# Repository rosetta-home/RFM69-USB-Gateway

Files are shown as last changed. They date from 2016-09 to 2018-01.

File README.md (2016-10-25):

# RFM69-USB-Gateway
This is a USB gateway for the RFM69 FSK module. Incoming wireless data is sent to the host computer over serial.

<p align="center">
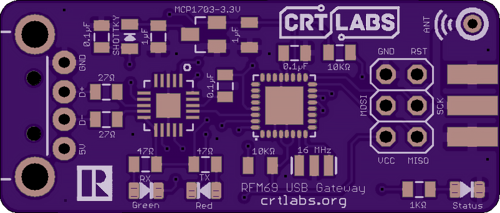
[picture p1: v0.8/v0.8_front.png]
OSH Park PCB render - front
  
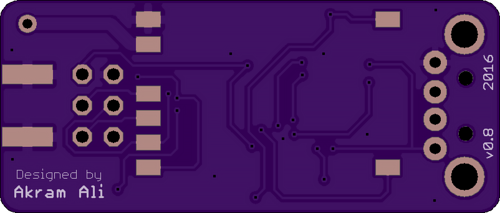
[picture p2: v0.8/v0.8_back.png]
OSH Park PCB render - back
  
</p>

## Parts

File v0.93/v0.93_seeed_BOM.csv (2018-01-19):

Designator | Manufacturer Part Number | Quantity
C1, C5, C6 | CC0805KRX7R9BB104 | 3
R1 | RC0805FR-0710KL | 1
R7 | RC0805FR-0710KL | 1
X1 | CSTCE16M0V53-R0 | 1
R2 | RC0805FR-071KL | 1
C2, C4 | CC0805ZRY5V8BB105 | 2
R3, R5 | RC0805FR-0727RL | 2
R4, R6 | RC0805FR-0747RL | 2
U2 | ATMEGA328P-MU | 1
FT231XQ-R | FT231XQ-R | 1
RX | LG R971-KN-1 | 1
IC3 | MCP1703T-3302E/CB | 1
U1 | RFM69HCW | 1
TX | LG R971-KN-1 | 1
D | SD0805S040S0R5 | 1
U$2 | LG R971-KN-1 | 1

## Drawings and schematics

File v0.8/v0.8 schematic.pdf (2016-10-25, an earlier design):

U2

A

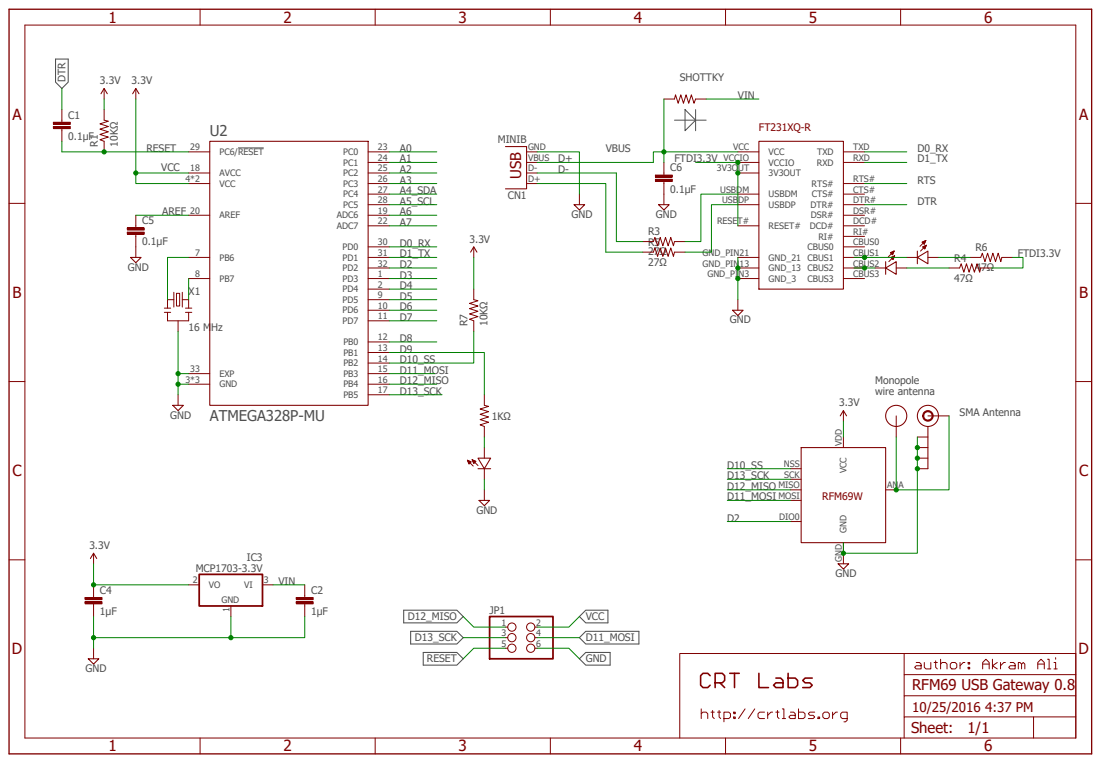
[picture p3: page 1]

VCC VDD GND GND DIO0

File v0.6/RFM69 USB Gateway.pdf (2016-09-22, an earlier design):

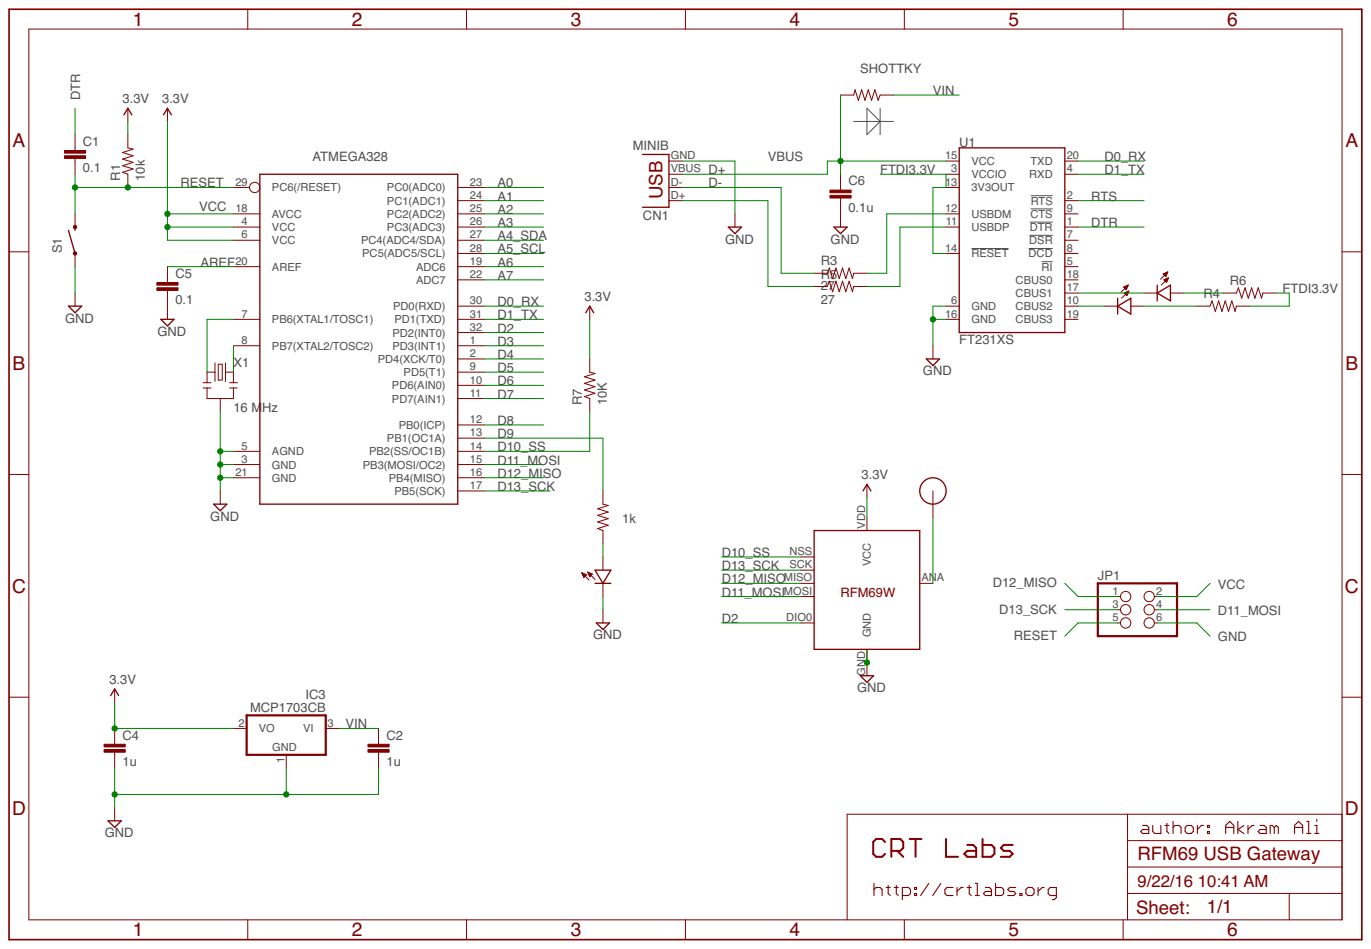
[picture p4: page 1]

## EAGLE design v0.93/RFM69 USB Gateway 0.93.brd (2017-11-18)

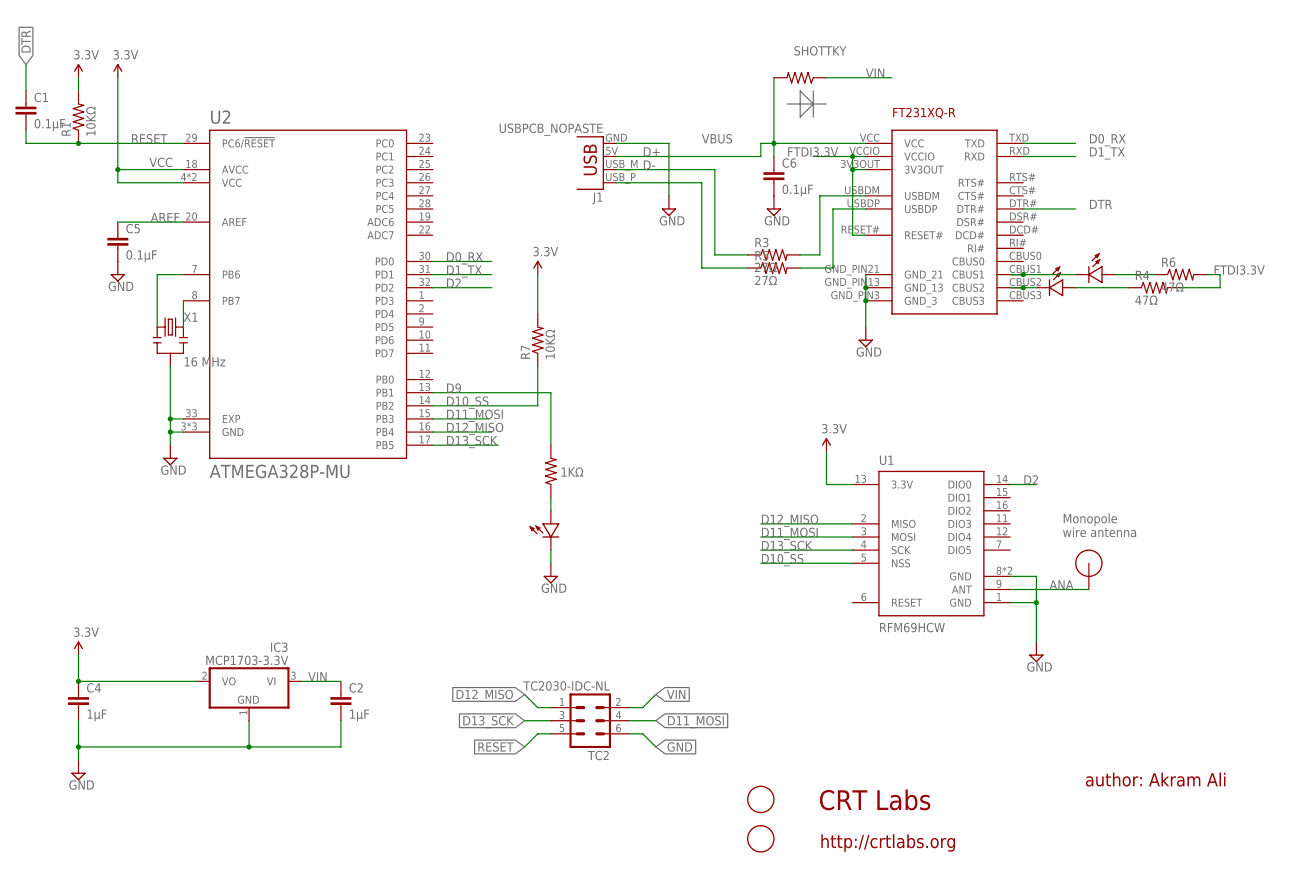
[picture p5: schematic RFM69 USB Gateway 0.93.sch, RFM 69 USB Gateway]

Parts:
C1, C5, C6: 0.1μF; 0805; MPN CC0805KRX7R9BB104
C2, C4: 1μF; 0805; MPN CC0805ZRY5V8BB105
D: SHOTTKY; 0805; MPN SD0805S040S0R5
FT231XQ-R: FT231XQ-R; FTDI_FT231XQ-R_PACKAGE; MPN FT231XQ-R
IC3: MCP1703-3.3V; SOT23; MPN MCP1703T-2502E/CB
J1: USBPCB_NOPASTE; USB-A-PCB-NOPASTE
R1, R7: 10KΩ; 0805; MPN RC0805FR-0710KL
R2: 1KΩ; 0805; MPN RC0805FR-071KL
R3, R5: 27Ω; 0805; MPN RC0805FR-0727RL
R4, R6: 47Ω; 0805; MPN RC0805FR-0747RL
RX: Green; 0805-LED; MPN LG R971-KN-1
TC2: TC2030-IDC-NL
TX: Red; 0805-LED; MPN LG R971-KN-1
U1: RFM69HCW; RFM69HCW-XXXS2; MPN RFM69HW
U2: ATMEGA328P-MU; QFN50P500X500X100-33N; MPN ATmega328P-MU
U$2: Status; 0805-LED; MPN LG R971-KN-1
U$3, U$4: FIDUCIAL; FIDUCIAL_1MM
U$6: RFM12B_ANTENNA; RFM12B-ANTENNA
X1: 16 MHz; RESONATOR-SMD; MPN CSTCE16M0V53-R0

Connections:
ANA: U1.9 (ANT), U$6.P$1
AREF: C5.1, U2.20 (AREF)
D0_RX: FT231XQ-R.TXD, U2.30 (PD0)
D1_TX: FT231XQ-R.RXD, U2.31 (PD1)
D2: U1.14 (DIO0), U2.32 (PD2)
D9: R2.2, U2.13 (PB1)
D10_SS: R7.1, U1.5 (NSS), U2.14 (PB2)
D11_MOSI: TC2.4, U1.3 (MOSI), U2.15 (PB3)
D12_MISO: TC2.1, U1.2 (MISO), U2.16 (PB4)
D13_SCK: TC2.3, U1.4 (SCK), U2.17 (PB5)
D+: J1.USB_P (D+), R5.1
D-: J1.USB_M (D-), R3.1
DTR: C1.1, FT231XQ-R.DTR#
FTDI3.3V: FT231XQ-R.3V3OUT, FT231XQ-R.RESET#, FT231XQ-R.VCCIO, R4.2, R6.2
GND: C2.2, C4.2, C5.2, C6.2, FT231XQ-R.GND_PIN3 (GND_3), FT231XQ-R.GND_PIN13 (GND_13), FT231XQ-R.GND_PIN21 (GND_21), IC3.1 (GND), J1.GND, TC2.6, U1.1 (GND), U1.8 (GND), U1.10 (GND), U2.3 (GND), U2.5 (GND), U2.21 (GND), U2.33 (EXP), U$2.MINUS, X1.2
unnamed: U2.7 (PB6), X1.1
unnamed: R2.1, U$2.PLUS
unnamed: FT231XQ-R.USBDM, R3.2
unnamed: FT231XQ-R.USBDP, R5.2
unnamed: FT231XQ-R.CBUS1, RX.MINUS
unnamed: FT231XQ-R.CBUS2, TX.MINUS
unnamed: R4.1, TX.PLUS
unnamed: R6.1, RX.PLUS
unnamed: U2.8 (PB7), X1.3
RESET: C1.2, R1.1, TC2.5, U2.29 (PC6/!RESET)
VBUS: C6.1, D.2, FT231XQ-R.VCC, J1.5V (VBUS)
VCC: C4.1, IC3.2 (VO), R1.2, R7.2, U1.13 (3.3V), U2.4 (VCC), U2.6 (VCC), U2.18 (AVCC)
VIN: C2.1, D.1, IC3.3 (VI), TC2.2

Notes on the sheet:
CRT Labs
author: Akram Ali
http://crtlabs.org
Monopole wire antenna

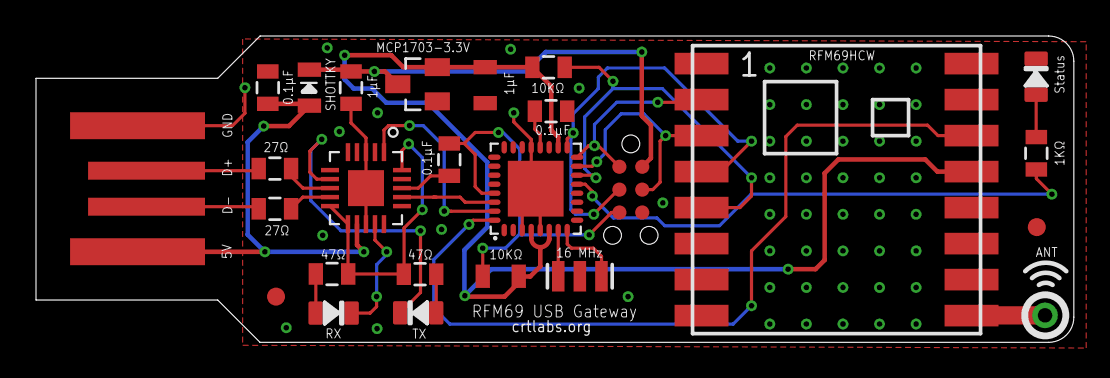
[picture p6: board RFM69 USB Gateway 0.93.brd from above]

Board: 2 copper layers, 57.7 x 17.0 mm, 26 parts (0 on the bottom side), 28 nets.

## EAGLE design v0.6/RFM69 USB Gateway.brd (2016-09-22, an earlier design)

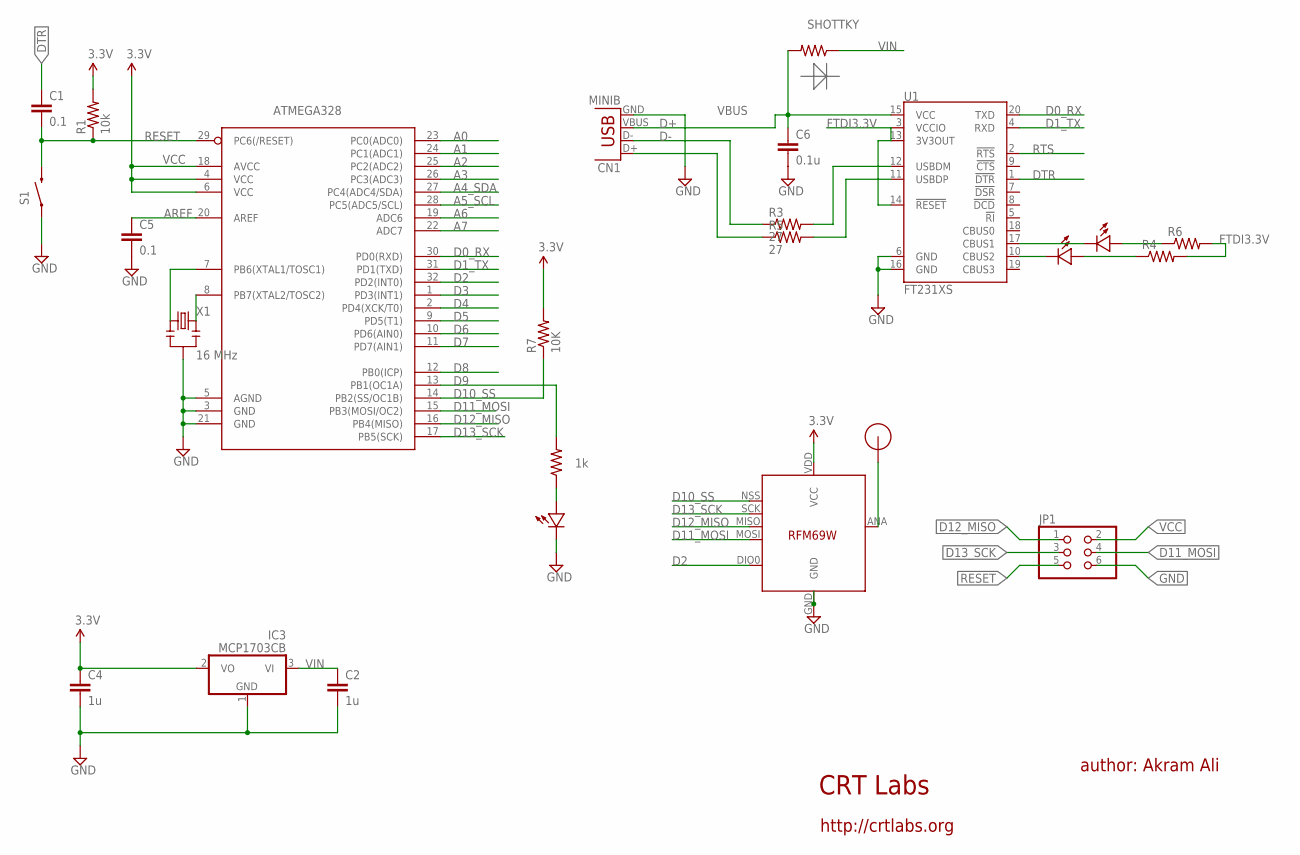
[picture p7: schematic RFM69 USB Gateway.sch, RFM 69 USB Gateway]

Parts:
ATMEGA328: ATMega-328; TQFP32-08
C1, C5: 0.1; 0805
C2, C4: 1u; 0805
C6: 0.1u; 0805
CN1: MINIB; USB-A-H
D: SHOTTKY; 0805
IC3: MCP1703CB; SOT23
JP1: PINHD-2X3; 2X03
R1: 10k; 0805
R2: 1k; 0805
R3, R5: 27; 0805
R4, R6: RESISTOR0805-RES; 0805
R7: 10K; 0805
S1: SWITCH-MOMENTARY-2SMD-ALT01; TACTILE-SWITCH-SMD-ALT01
U1: FT231XS; SSOP20_L
U$1: RFM12B_ANTENNA; RFM12B-ANTENNA
U$2, U$4, U$7: LED0805; 0805-LED
U$5: RFM69; RFM69W-MINPADS
X1: 16 MHz; RESONATOR-SMD

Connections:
A0: ATMEGA328.23 (PC0(ADC0))
A1: ATMEGA328.24 (PC1(ADC1))
A2: ATMEGA328.25 (PC2(ADC2))
A3: ATMEGA328.26 (PC3(ADC3))
A4_SDA: ATMEGA328.27 (PC4(ADC4/SDA))
A5_SCL: ATMEGA328.28 (PC5(ADC5/SCL))
A6: ATMEGA328.19 (ADC6)
A7: ATMEGA328.22 (ADC7)
AREF: ATMEGA328.20 (AREF), C5.1
D0_RX: ATMEGA328.30 (PD0(RXD)), U1.20 (TXD)
D1_TX: ATMEGA328.31 (PD1(TXD)), U1.4 (RXD)
D2: ATMEGA328.32 (PD2(INT0)), U$5.DIO0
D3: ATMEGA328.1 (PD3(INT1))
D4: ATMEGA328.2 (PD4(XCK/T0))
D5: ATMEGA328.9 (PD5(T1))
D6: ATMEGA328.10 (PD6(AIN0))
D7: ATMEGA328.11 (PD7(AIN1))
D8: ATMEGA328.12 (PB0(ICP))
D9: ATMEGA328.13 (PB1(OC1A)), R2.2
D10_SS: ATMEGA328.14 (PB2(SS/OC1B)), R7.1, U$5.NSS (SEL)
D11_MOSI: ATMEGA328.15 (PB3(MOSI/OC2)), JP1.4, U$5.MOSI
D12_MISO: ATMEGA328.16 (PB4(MISO)), JP1.1, U$5.MISO
D13_SCK: ATMEGA328.17 (PB5(SCK)), JP1.3, U$5.SCK
D+: CN1.D+, R5.1
D-: CN1.D-, R3.1
DTR: C1.1, U1.1 (!DTR)
FTDI3.3V: R4.2, R6.2, U1.3 (VCCIO), U1.13 (3V3OUT), U1.14 (!RESET)
GND: ATMEGA328.3 (GND), ATMEGA328.5 (AGND), ATMEGA328.21 (GND), C2.2, C4.2, C5.2, C6.2, CN1.GND, IC3.1 (GND), JP1.6, S1.1, S1.2 (1), U1.6 (GND), U1.16 (GND), U$2.MINUS, U$5.GND, X1.2
unnamed: ATMEGA328.7 (PB6(XTAL1/TOSC1)), X1.1
unnamed: R2.1, U$2.PLUS
unnamed: U$1.P$1, U$5.ANA (ANT)
unnamed: R3.2, U1.12 (USBDM)
unnamed: R5.2, U1.11 (USBDP)
unnamed: U1.17 (CBUS1), U$4.MINUS
unnamed: U1.10 (CBUS2), U$7.MINUS
unnamed: R4.1, U$7.PLUS
unnamed: R6.1, U$4.PLUS
unnamed: ATMEGA328.8 (PB7(XTAL2/TOSC2)), X1.3
RESET: ATMEGA328.29 (PC6(/RESET)), C1.2, JP1.5, R1.1, S1.3 (2), S1.4 (2)
RTS: U1.2 (!RTS)
VBUS: C6.1, CN1.VBUS, D.2, U1.15 (VCC)
VCC: ATMEGA328.4 (VCC), ATMEGA328.6 (VCC), ATMEGA328.18 (AVCC), C4.1, IC3.2 (VO), JP1.2, R1.2, R7.2, U$5.VDD (VCC)
VIN: C2.1, D.1, IC3.3 (VI)

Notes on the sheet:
CRT Labs
author: Akram Ali
http://crtlabs.org

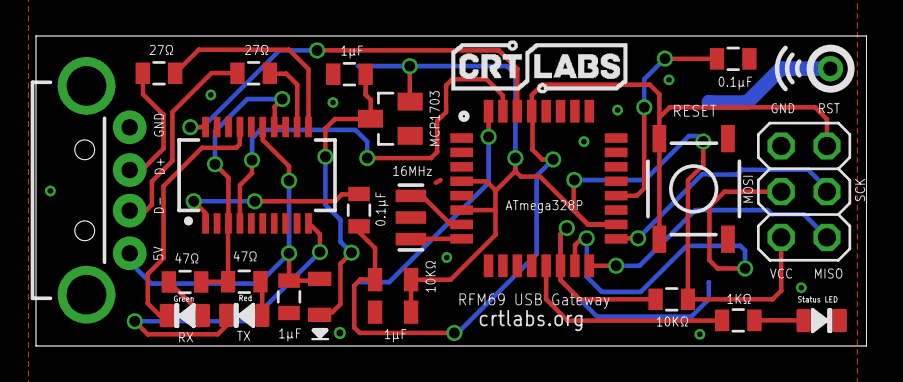
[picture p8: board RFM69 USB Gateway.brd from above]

Board: 2 copper layers, 46.1 x 17.2 mm, 25 parts (1 on the bottom side), 28 nets.

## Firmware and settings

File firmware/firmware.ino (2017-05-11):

#include <RFM69.h>         //get it here: http://github.com/lowpowerlab/rfm69
#include <SPIFlash.h>      //get it here: http://github.com/lowpowerlab/spiflash
#include <SPI.h>           //comes with Arduino IDE (www.arduino.cc)
#include "config.h"

#define NETWORKID     101
#define FREQUENCY     RF69_915MHZ //Match this with the version of your Moteino! (others: RF69_433MHZ, RF69_868MHZ)
#define IS_RFM69HW    //uncomment only for RFM69HW! Leave out if you have RFM69W!
#define LED             9
#define FLASH_CS        8
#define SERIAL_BAUD 115200
#define SERIAL_EN     //comment out if you don't want any serial verbose output
#define ACK_TIME       30  // # of ms to wait for an ack
//*****************************************************************************************************************************

RFM69 radio;
SPIFlash flash(FLASH_CS, 0xEF30); //EF40 for 16mbit windbond chip
char data[100];
char _rssi[5];

void setup()
{
  pinMode(10, OUTPUT);
  Serial.begin(115200);

  radio.initialize(FREQUENCY,NODEID,NETWORKID);
#ifdef IS_RFM69HW
  radio.setHighPower(); //uncomment only for RFM69HW!
#endif
  radio.encrypt(ENCRYPTKEY);
  flash.initialize();
}

void loop()
{
  if (radio.receiveDone())
  {
    int rssi = radio.RSSI;

    if (radio.DATALEN > 0)
    {
      for (byte i = 0; i < radio.DATALEN; i++)
        data[i] = (char)radio.DATA[i];
    }

    dtostrf(rssi, 3, 0, _rssi);
    strcat(data, ",r:");
    strcat(data, _rssi);

    if (radio.ACKRequested())
    {
      byte theNodeID = radio.SENDERID;
      radio.sendACK();

      Serial.println(data);
      delay(1);

      memset(data, 0, sizeof data);
      memset(_rssi, 0, sizeof _rssi);

      Blink(LED,10);
    }
  }
}

void Blink(byte PIN, int DELAY_MS)
{
  pinMode(PIN, OUTPUT);
  digitalWrite(PIN,HIGH);
  delay(DELAY_MS);
  digitalWrite(PIN,LOW);
}

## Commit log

2016-07-01 Eagle files for USB gateway
    v0.2
    [RFM69 USB Gateway.brd, RFM69 USB Gateway.sch]
2016-07-15 USB jack adjustments
    v0.3 - Adjusted edge of board a little to accommodate groove of USB jack
2016-07-21 Added ISP header and reset button
    v0.4
    - ISP header
    - Reset button
    - Silk screen for all components
    - Slight rearrangement
    [RFM69 USB Gateway.brd, RFM69 USB Gateway.sch]
2016-07-21 Fixed overlapping traces
    [RFM69 USB Gateway.brd]
2016-07-21 OSH Park PCB layout
2016-08-03 Added pullup on CS line
    10K pullup on CS for allowing ISP programming
    Changed all components to 0805 size
    [RFM69%20USB%20Gateway.brd, RFM69%20USB%20Gateway.sch]
2016-08-03 Silkscreen minor edits
    [RFM69%20USB%20Gateway.brd]
2016-08-03 Added pullup on CS (pin 10)
    10K pullup on CS (RFM69) to avoid issues during ISP programming
    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
    [RFM69 USB Gateway.brd, RFM69 USB Gateway.sch]
2016-08-03 PCB render from oshpark.com
2016-09-08 PDF schematic added
2016-09-22 v0.6 - fixed auto reset, adjusted traces
    Added 0.1 uF cap on reset, series with DTR (allows auto reset via FTDI)
    Moved some components to accommodate the cap
    Adjusted several traces
    Made GND vias more consistent in size
    [RFM69 USB Gateway.brd, RFM69 USB Gateway.sch]
2016-09-22 Updated the PDF schematic
    v0.6
    [RFM69 USB Gateway.sch]
2016-09-22 Adjusted D- trace
2016-09-22 Minor silkscreen adjustments
    [RFM69 USB Gateway.brd]
2016-09-22 Added CRT Labs logo
    [RFM69 USB Gateway.brd]
2016-09-22 Added back PCB render
2016-09-22 v0.7 - added SMA connector
    Moved some components around to accommodate for SMA connector and clean
    up some traces
    [RFM69 USB Gateway 0.7.brd, RFM69 USB Gateway 0.7.sch]
2016-09-22 Touch up schematic
    [RFM69 USB Gateway 0.7.sch]
2016-09-22 Deleted old schematic
2016-09-22 Added v0.7 renders
    v0.7 has SMA antenna, some components moved a bit to accommodate for
    it. Board length is slightly longer than v0.6, but everything else is
    the same.
    [RFM69 USB Gateway 0.7.brd, RFM69 USB Gateway 0.7.sch]
2016-09-22 Rounded corners of board
    [RFM69 USB Gateway 0.7.brd, RFM69 USB Gateway 0.7.sch]
2016-10-18 v0.8 - Changed packages to QFN - **WIP**
    ! Traces not connected !
    [RFM69 USB Gateway 0.8.brd, RFM69 USB Gateway 0.8.sch]
2016-10-25 Routed all traces
    Rearranged components on the board
    [RFM69 USB Gateway 0.8.brd, RFM69 USB Gateway 0.8.sch]
2016-10-25 Deleted shrug emoji because no space :( but oh well ¯\_(ツ)_/¯
    [RFM69 USB Gateway 0.8.brd]
2016-10-25 Unsmashed and updated all component values
    [RFM69 USB Gateway 0.8.brd, RFM69 USB Gateway 0.8.sch]
2016-10-25 Fixed silkscreen
    Changed all fonts to vector; silkscreen now on layer 121, adjusted some
    components and traces
    [RFM69 USB Gateway 0.8.brd, RFM69 USB Gateway 0.8.sch]
2016-10-25 Adjusted silkscreen
    [RFM69 USB Gateway 0.8.brd, RFM69 USB Gateway 0.8.sch]
2016-10-25 Added REALTOR R to silkscreen
    [RFM69 USB Gateway 0.8.brd]
2016-10-25 Organized folders
    [RFM69 USB Gateway 0.7.brd, RFM69 USB Gateway 0.7.sch, RFM69 USB Gateway.brd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]
2016-10-25 Added PDF schematic for v0.8
2016-10-25 Minor trace adjustments
    [RFM69 USB Gateway 0.8.brd]
2017-02-06 v0.9 - Integrated USB jack into PCB
    - removed USB A jack and integrated into PCB. 2.4mm thickness required
    for a tight fit into USB port.
    - made VCC traces slightly thicker.
    [RFM69 USB Gateway 0.9.brd, RFM69 USB Gateway 0.9.sch]
2017-02-07 v0.91 moving RFM69 to top side
    traces still incomplete
    [RFM69 USB Gateway 0.91.brd, RFM69 USB Gateway 0.91.sch]
2017-02-07 Made ground pours on bottom more even
    Added extra stitching vias; changed very thin line-like pours to thicker
    and fatter (ish) ones; minor touchups
    [RFM69 USB Gateway 0.9.brd]
2017-02-13 Connected all traces
    [RFM69 USB Gateway 0.91.brd]
2017-03-16 Minor firmware update
    LED will only blink after ACK is requested and sent
2017-03-22 v0.92 - design update
    - Removed ISP headers (flash using MLF/QFN socket - for advanced users
    only) use v0.8 or v0.9 for ISP headers
    - Removed SMA pads (just use wire monopole 82mm for 915MHz)
    - Replaced RFM69HW with RFM69HCW
    - Reduced overall size of board
    - Rerouted several traces to fit new design
    - Massive GND plane stitching
    - Silkscreen adjustments
    - Schematic adjustments
    - Accounted for major errors in DRC and ERC (ignore drill size, trace
    width and clearance)
    - Relocated LED
    [RFM69 USB Gateway 0.92.brd, RFM69 USB Gateway 0.92.sch]
2017-03-22 Relocated a via
    for better silkscreen
    [RFM69 USB Gateway 0.92.brd]
2017-03-29 adding bom for v.92
    [RFM69 USB Gateway 0.92-BOM.csv]
2017-03-29 adding mpns to schematic
    [RFM69 USB Gateway 0.92.sch]
2017-03-30 updated mpn to ATmega328P-MU
    [RFM69 USB Gateway 0.92-BOM.csv]
2017-03-30 synchronized brd file
    [RFM69 USB Gateway 0.92.brd]
2017-04-03 Fixed mirrored logo
    lol how did that happen
    [RFM69 USB Gateway 0.92.brd]
2017-11-18 v0.93 update
    - Added tag connect ISP header for programming
    - board dimensions slightly increased to accomodate tag connect
    - Adjusted several traces to accomodate new header
    - Increased all via drill sizes to 12 mil (0.3mm)
    - Reduced thickness of USB part from 12.54mm to 12.30mm
    - minor silk screen adjustments
    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
    [RFM69 USB Gateway 0.93.brd, RFM69 USB Gateway 0.93.sch]
2017-12-05 Added gerbers and BOM
    [v0.93_seeed_BOM.csv]
2018-01-19 BOM update
    [v0.93_seeed_BOM.csv]

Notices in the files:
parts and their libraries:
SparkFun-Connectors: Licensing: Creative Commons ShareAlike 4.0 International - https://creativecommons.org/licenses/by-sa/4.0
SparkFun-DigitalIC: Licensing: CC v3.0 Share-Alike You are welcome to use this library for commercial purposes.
